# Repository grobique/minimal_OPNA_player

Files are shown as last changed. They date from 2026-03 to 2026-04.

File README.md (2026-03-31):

# minimal_OPNA_player
YM2608 (OPNA) player, using minimal amount of hardware to play PC98 music in .VGM and .S98 formats

## Overview
This is a **lightweight** (in current form) opensource project designed to interface a Yamaha YM2608 (OPNA) with an STM32F103C6T6 microcontroller, one of the cheapest ones. You can literally make it on a breadboard!

## Features
- Real hardware! As authentic as could be in "minimal" (also may known as "hell yeah")
- No need in external clock source!
- Micro SD card as a storage. Imagine how many tunes you can put in there!
- Basic components! Well, aside from YM2608 and its DAC, YM3016.
- Comments in (almost) ***EVERY SINGLE LINE*** of code!

## To do:
- Fix VGM tempo losses. These rush just a tiny bit, but I don't like it either way
- Put the libraries in here. Messing with preinstalled libs is... meh...

## Schematic
Refer to **[`schematic_v1.pdf`](./schematic_v1.pdf)** for pinouts and connections.

## Installation
Install ArduinoIDE, download STM32 core from [here](https://github.com/stm32duino/Arduino_Core_STM32), install [STM32CubeProg](https://www.st.com/en/development-tools/stm32cubeprog.html), install SdFat and GyverOLED libraries (available in library manager). Bam, done!
BEFORE flashing, make sure to edit SdFat configuration in `Documents\Arduino\libraries\SdFat\src\SdFatConfig.h`:
```
line 96 -  #define ENABLE_ARDUINO_SERIAL 0   will free some memory, allowing to disable Serial
line 169 - #define SPI_DRIVER_SELECT 2       will enable software SPI. i have no idea why SPI2 hangs the chip.
```
Yes, it reqires software SPI. I still have no idea why my microcontroller hangs dead when I'm trying to use hardware SPI2.

Compilation - Smallest (-Os) with LTO



## "Dumps", because I can.
Vorbis, quality 10, 88.2KHz.

[Sleeping Terror](https://drive.google.com/file/d/1qs6JLUKrdlb78_PDLtCmRrMHYK6tYY8U/view?usp=sharing) (gdrive)

## Contributing
please do.

## What's next?
I dunno lul. I wanna make a port to STM32F4 with several firmware versions. A PCB, for the love of our lord and saviour Shinki. Maybe I'll make it chew .M/.M2 files from Kajihara's driver. Since it's still plugged in my Line In, nothing stops me from making it a MIDI controlled synth. Hell yeah.

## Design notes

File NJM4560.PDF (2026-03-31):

# NJM4560

# MEMO

[CAUTION]
The specifications on this databook are only given for information , without any guarantee as regards either mistakes or omissions. The application circuits in this databook are described only to show representative usages of the product and not intended for the guarantee or permission of any right including the industrial rights.

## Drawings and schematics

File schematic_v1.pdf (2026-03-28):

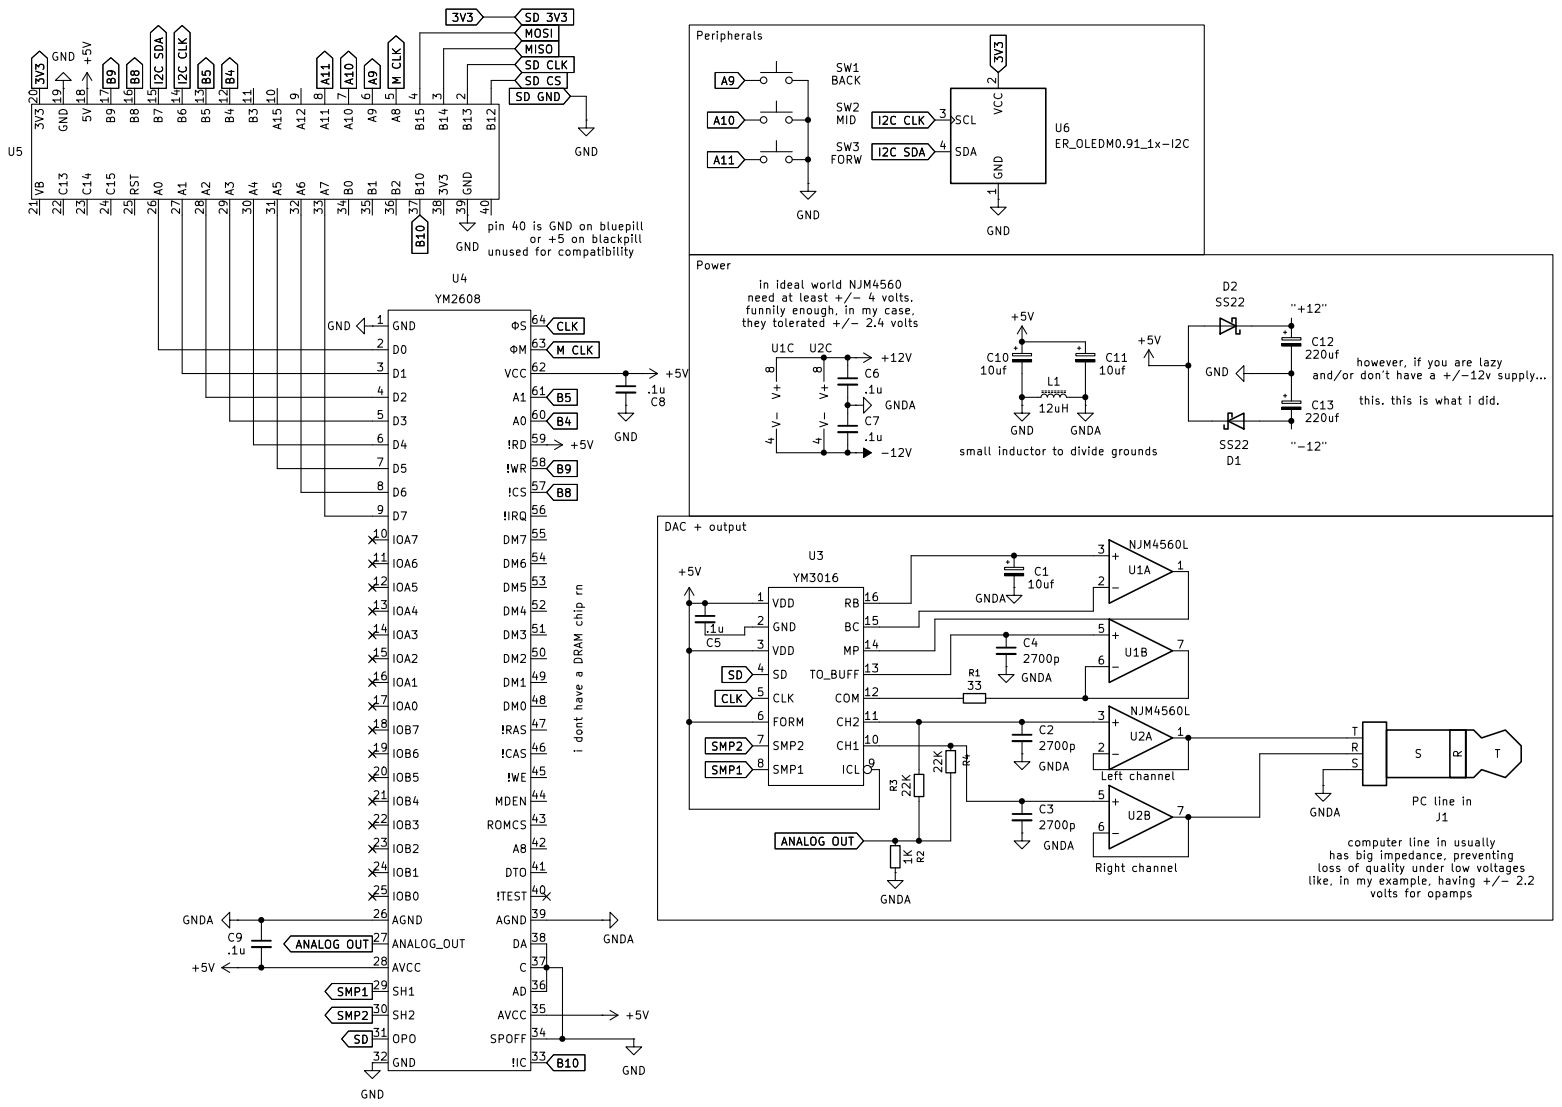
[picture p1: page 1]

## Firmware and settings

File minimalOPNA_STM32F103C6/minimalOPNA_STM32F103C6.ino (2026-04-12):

#include <Arduino.h>         
#include <SPI.h>             // thats for SdFat
#include <Wire.h>            // for I2C. just in case.
#include "SdFat.h"           // sd card stuff. i hope ya have one spare
#include <GyverOLED.h>       // Alex Gyver OLED library. lightweigh, reliable, fast enough

//      YM2608 pin setup
#define YM_A0   PB4  // YM2608 A0, for selecting register banks (port 0 or port 1)
#define YM_A1   PB5  // YM2608 A1, 0 - writing register data, 1 - write data
#define YM_CS   PB8  // YM2608 chip select pin, ACTIVE LOW
#define YM_WR   PB9  // YM2608 strobe pulse for writing data. ACTIVE LOW
#define YM_IC   PB10 // YM2608 initial clear, used as hardware reset. ACTIVE LOW

#define YM_RD   PB11 // YM2608 read *from* synth. basically, unused here, because i pulled it to VCC. ACTIVE LOW
// note: data bus is on PA0-PA7. these pins are in the same port, makes it easier to set them all with minimal latency. hardcoded a little below
// note: PA8 is a 8 MHz clock for YM2608. (mco)

//      software SPI setup (matches SPI2)
#define SD_CS_PIN   PB12 // sd chip select pin
#define SD_SCK_PIN  PB13 // clock 
#define SD_MISO_PIN PB14 // master in slave out
#define SD_MOSI_PIN PB15 // master out slave in
//                            !!!!!  ATTENTION  !!!!!
//                            DO THINGS BELOW! I SWEAR TO GOD
// \Documents\Arduino\libraries\SdFat\src\SdFatConfig.h:
// line 96 -  #define ENABLE_ARDUINO_SERIAL 0            will free some memory, allowing to disable Serial
// line 169 - #define SPI_DRIVER_SELECT 2                will enable software SPI. i have no idea why SPI2 hangs the chip.

// button setup
#define BTN_LEFT  PA9  // backwards
#define BTN_OK    PA10 // OK/back to menu button
#define BTN_RIGHT PA11 // forward

//      some globals and classes
// software spi class
SoftSpiDriver<SD_MISO_PIN, SD_MOSI_PIN, SD_SCK_PIN> mySoftSpi;
// setting up SdFat to use our software spi on 4 mhz clock
#define SD_CONFIG SdSpiConfig(SD_CS_PIN, DEDICATED_SPI, SD_SCK_MHZ(4), &mySoftSpi)

SdFat SD;       // main object for working with fat32
FsFile vgmFile; // file object with our track data

// OLED init
// using no buffer mode, saves 1K of RAM and reduces chances of lags
GyverOLED<SSD1306_128x64, OLED_NO_BUFFER> oled;

//      global variables
enum State { STATE_BROWSER, STATE_PLAY }; // two states - menu (list of tracks) and player
State currentState = STATE_BROWSER;       // main menu during bootup

bool isS98 = false;               // if true - S98 file is playing, if false - VGM is playing
uint32_t data_offset = 0x40;      // data offset where music data begins
uint32_t loop_offset = 0;         // offset where to jump when track ends
uint32_t s98_tick_us = 10000;     // single s98 tick length in microseconds

uint32_t current_samples = 0;     // sample counter to calculate track length in seconds (funnily enough, 44100 = 1s. nothing to do with *actual* discretization frequency of YM2608 (55.5K))
uint32_t total_samples = 0;       // VGM file length in samples
uint32_t current_us = 0;          // us counter for calculating the length of S98 file
uint32_t lastDrawTime = 0;        // last screen update timer

uint32_t track_sync_timer = 0;    // absolute timer, used to send data in YM2608 as precisely as i can

bool isPaused = false;            // pause flag. fun fact! it hangs notes, because YM2608 does not recieve a "note off" command
bool action_next = false;         // next track check
bool action_prev = false;         // prev track check
bool action_menu = false;         // middle button check

uint16_t totalFiles = 0;          // supported file counter in root dir
uint16_t fileIndex = 0;           // cursor index
uint16_t displayTopIdx = 0;       // for scrolling - shows the first file *displayed on screen*

char currentFilename[32] = "";       // track filename buffer
char metaTitle[21] = "Unknown Title"; // metadata track name buffer
char metaComposer[21] = "Unknown";    // metadata composer name buffer

//      some hardware stuff for YM2608

// setting up a clock signal for YM2608
void setupMCO() {
  // making a PA8 as push-pull, 50mhz
  GPIOA->CRH = (GPIOA->CRH & 0xFFFFFFF0) | 0x0000000B; 
  // enabling MCO, HSI, using external clock source (this shiny 8mhz cristal, in case of STM32F103. no, not the 32768hz one, thats realtime clock you silly goober)
  RCC->CFGR = (RCC->CFGR & ~(0x07 << 24)) | (0x05 << 24); 
}

//      pain kicks in
// sending data in YM2608 while trying to keep latencies from datasheet
void writeYM(uint8_t port, uint8_t reg, uint8_t data) {
  // stage 1 - choosing registers
  digitalWrite(YM_A1, port); // choosing port: 1 - FM1-FM3 + SSG + RSS, 0 - FM4-FM6 + ADPCM. YM2608 is YM2203(OPN) compatible, remember that?
  digitalWrite(YM_A0, LOW);  // "im gonna send you the register number address rn"
  
  // grabbing our port A, zeroing lower 8 bits, and writing register address
  GPIOA->ODR = (GPIOA->ODR & 0xFFFFFF00) | reg;
  delayMicroseconds(2); // setup time for volatges to settle

  digitalWrite(YM_CS, LOW);  // enbling the chip, making CS 0
  digitalWrite(YM_WR, LOW);  // making it WRITE data
  delayMicroseconds(2);      // giving some time to settle again
  digitalWrite(YM_WR, HIGH); // disbling data writing
  digitalWrite(YM_CS, HIGH); // disabling chip
  delayMicroseconds(4);      // approx. 17 clock cycles to apply the address

  // stage 2 - writing data in that register
  digitalWrite(YM_A0, HIGH); // "im sending the DATA to that address"
  GPIOA->ODR = (GPIOA->ODR & 0xFFFFFF00) | data; // writing port A data to send to YM2608
  delayMicroseconds(2); // settle time

  digitalWrite(YM_CS, LOW);  // enabling the chip
  digitalWrite(YM_WR, LOW);  // WRITING DATA
  delayMicroseconds(2);      // girls are preparing... please wait warmly
  digitalWrite(YM_WR, HIGH); // lowering the WRITE signal
  digitalWrite(YM_CS, HIGH); // releasing the chip in the wild
  delayMicroseconds(12);     // letting it proccess the audio data for approx. 83 clock cycles, as instructed in the datasheet
}

//      hardware reset
void resetYM() {
  digitalWrite(YM_IC, LOW);  // setting initial clear as 0, enabling it
  delay(20);                 // holding for a bit
  digitalWrite(YM_IC, HIGH); // and getting it back to 1, disabling
  delay(20);                 // giving it ome time to start
}

//      some button stuff
bool btn_l_last = HIGH, btn_ok_last = HIGH, btn_r_last = HIGH; // savestates for buttons, pulled up to HIGH interanally

//      checking the buttons, debounce included! (it sucks, millis() = UEEUGHH)
void checkButtons() {
  bool l = digitalRead(BTN_LEFT);  // reading LEFT button
  bool ok = digitalRead(BTN_OK);   // reading MIDDLE (aka OK/MENU, however ya call it m8) button
  bool r = digitalRead(BTN_RIGHT); // reading RIGHT button

  // if left btn got LOW and was HIGH                                                                                                             high does not mean "stoned" you doofus
  if (l == LOW && btn_l_last == HIGH) { action_prev = true; delay(50); } // falgging it and debouncing
  
  // middle button short press
  if (ok == LOW && btn_ok_last == HIGH) { 
    if (currentState == STATE_BROWSER) action_menu = true; // if in menu - plays selected file
    else {
      isPaused = !isPaused;                             // if in player - play/pause
      delay(50); 
      if (!isPaused) {
        track_sync_timer = micros();      // debounce delay compensation
        lastDrawTime = millis();
      }
    }
  }
  
  // long middle button press
  if (ok == LOW && currentState == STATE_PLAY) {
    uint32_t holdTime = millis(); // hold timer start
    while(digitalRead(BTN_OK) == LOW) { // while it pressed:
      if (millis() - holdTime > 700) {  // and .7s passed
        action_menu = true;             // going back to menu
        break;                          // exiting the cycle!
      }
    }
  }

  // right button press
  if (r == LOW && btn_r_last == HIGH) { action_next = true; delay(50); }

  // saving states for next function call
  btn_l_last = l; btn_ok_last = ok; btn_r_last = r;
}

//      pain 2: electric boogaloo
//      synchronization
// this changes delay() function, except it does not block anything
void syncWaitUs(uint32_t us) {
  // infinite cycle, while system micros() timer and our target timer are less than our required delay
  while ((micros() - track_sync_timer) < us) {
    checkButtons(); // as we are waiting, we need to check how buttons are doing
    // if a button is pressed, breaking the pause
    if (action_next || action_prev || action_menu) return;
  }
  // adding that pause to our absolute timer
  track_sync_timer += us;
}

//      file and meta reading procedures

// reads two bytes to shove them in a single 32bit number
uint32_t read32() {
  uint32_t val = 0;
  vgmFile.read(&val, 4);
  return val;
}

// reading GD3 tags. these are used in VGMs
void readGD3String(char* buf, int maxLen) {
  int i = 0;
  while (true) {
    // GD3s are saven in UTF-16
    uint16_t c = vgmFile.read() | (vgmFile.read() << 8);
    if (c == 0x0000) { buf[i] = '\0'; break; } // two 00 bytes - end of line
    // reading only ASCII symbols
    if (i < maxLen - 1) { buf[i] = (char)(c & 0xFF); i++; }
  }
}

// S98 tag reader
void parseS98Tags(uint32_t tag_offset) {
  // clearing buffers
  strcpy(metaTitle, "Unknown");
  strcpy(metaComposer, "Unknown");
  if (tag_offset == 0) return; // if offset is 0, there's no tags, exiting
  
  vgmFile.seek(tag_offset); // jumping straight to tag block
  char buf[5];
  vgmFile.read(buf, 5); // reading our 5 byte marker closer to the end, [S98]
  if (strncmp(buf, "[S98]", 5) != 0) return; // if its not "[S98]", tags might be corrupted, exiting

  char line[64]; // one line buffer, 64 symbols
  while (vgmFile.available()) {
    int i = 0;
    while (vgmFile.available() && i < 63) { // reading 63 of them
      char c = vgmFile.read(); // taking 1 symbol
      if (c == '\n' || c == '\r') { // if we got line feed
        if (i == 0) continue; // skiping empty symbols
        else break;           // if the string isnt empty, exiting
      }
      line[i++] = c; // saving a symbol to a buffer
    }
    line[i] = '\0'; // closing a string with a zero byte. its not me, its C
    if (i == 0) break; // if we didnt read anything, then its end of file

    // if our string starts with "title="
    if (strncmp(line, "title=", 6) == 0) {
      strncpy(metaTitle, line + 6, 20); metaTitle[20] = '\0'; // copying everything in title buffer
    } 
    // same for composer
    else if (strncmp(line, "artist=", 7) == 0 || strncmp(line, "composer=", 9) == 0) {
      int offset = (line[0] == 'a') ? 7 : 9; // calculating the offset
      strncpy(metaComposer, line + offset, 20); metaComposer[20] = '\0'; // and copying in metaComposer
    }
  }
}

// counting the musical tracks here. once per boot
void scanFilesCount() {
  FsFile dir; dir.open("/"); // looking up what do we have in root
  FsFile file;
  totalFiles = 0; // zeroing the counter
  while (file.openNext(&dir, O_READ)) { // looking for files
    if (!file.isHidden() && !file.isDir()) { // ignoring folders and hidden stuff
      char name[32]; file.getName(name, sizeof(name)); // reading file name...
      // ...and exension. if .vgm or .s98, adding 1 to a counter
      if (strstr(name, ".vgm") || strstr(name, ".VGM") || strstr(name, ".s98") || strstr(name, ".S98")) totalFiles++;
    }
    file.close(); // closing file, picking up next one
  }
  dir.close(); // closing the folder
}
//      draw calls for OLED

// drawing main menu with our list of files
void drawBrowser() {
  oled.clear(); // screen clear
  oled.home();  // carriage goes in top left
  oled.print(F("== SELECT TRACK ==")); // header
  
  FsFile dir; dir.open("/"); // reading root
  FsFile file;
  uint16_t count = 0;

  // stage one - scrolling and looking for the first file thats being drawn
  while (file.openNext(&dir, O_READ)) {
    if (!file.isHidden() && !file.isDir()) {
      char name[32]; file.getName(name, sizeof(name));
      if (strstr(name, ".vgm") || strstr(name, ".VGM") || strstr(name, ".s98") || strstr(name, ".S98")) {
        if (count == displayTopIdx) break; // found it, closing the cycle (the file is STILL BEING OPEN)
        count++;
      }
    }
    file.close(); // closing the file, looking for the next one
  }

  // stage 2 - drawing 6 rows of files
  for (int i = 0; i < 6; i++) {
    if (!file.isOpen()) break; // if no more files - exiting
    char name[32]; file.getName(name, sizeof(name)); // grabbing file name
    
    oled.setCursor(0, i + 1); // carriage goes to rows 1 and 6
    
    // drawing a simple cursor next to selected file
    if (displayTopIdx + i == fileIndex) oled.print(F(">"));
    else oled.print(F(" ")); // or else drawing a space
    
    oled.print(name); // printing a file name
    file.close(); // closing the file

    // small cycle to see a next file for the list
    while (file.openNext(&dir, O_READ)) {
      if (!file.isHidden() && !file.isDir()) {
        char nextName[32]; file.getName(nextName, sizeof(nextName));
        if (strstr(nextName, ".vgm") || strstr(nextName, ".VGM") || strstr(nextName, ".s98") || strstr(nextName, ".S98")) break; 
      }
      file.close();
    }
  }
  dir.close(); // closing directory
}

// drawing time! every second
void drawPlayer() {
  if (millis() - lastDrawTime < 1000) return; // if 1s didnt pass yet - exiting
  lastDrawTime = millis(); // refreshing draw call timer

  oled.setCursor(0, 6); // moving our carriage to a row 6

  if (!isS98) { // if we are playing the vgm file
    uint32_t curSec = current_samples / 44100; // counting seconds that passed
    uint32_t totSec = total_samples / 44100;   // calculating track length
    
    // drawing time (mm:ss)
    oled.print(curSec / 60); oled.print(F(":")); 
    if ((curSec % 60) < 10) oled.print(F("0")); // sneakily adding a 0, if <10 seconds were played
    oled.print(curSec % 60);
    
    oled.print(F(" / "));
    
    // track length
    oled.print(totSec / 60); oled.print(F(":"));
    if ((totSec % 60) < 10) oled.print(F("0")); 
    oled.print(totSec % 60);
  } else { // if S98 is being played...
    uint32_t curSec = current_us / 1000000; // calculating from microseconds
    
    // i already forgot wht was i doing here, i think .s98 doesnt have track length stored in it. but at least we can count current time. im sowwy
    oled.print(curSec / 60); oled.print(F(":")); 
    if ((curSec % 60) < 10) oled.print(F("0")); 
    oled.print(curSec % 60);
    oled.print(F(" / --:--"));
  }
  
  oled.print(F("       ")); // drawing spaces to erase some stuff that could appear
}

//    starting the track
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
void loop() {
  checkButtons(); // checking how our buttons are doing

//      branch 1 - main meny, aka file list
  if (currentState == STATE_BROWSER) {
    if (action_prev) { // on LEFT press...
      if (fileIndex > 0) fileIndex--; // moving cursor up
      if (fileIndex < displayTopIdx) displayTopIdx = fileIndex; // scrolling up, if needed
      drawBrowser(); // redrawing
    }
    if (action_next) { // on RIGHT press...
      if (fileIndex < totalFiles - 1) fileIndex++; // moving cursor down
      if (fileIndex >= displayTopIdx + 6) displayTopIdx = fileIndex - 5; // scrolling down if needed
      drawBrowser(); // redrawing
    }
    if (action_menu) playSelectedFile(); // on OK press - playing selected file
    
    // resetting button flags
    action_next = action_prev = action_menu = false;
    return; // going back to beginning of loop()
  }

//          branch 2 - player loop
  if (currentState == STATE_PLAY) {
    
    // if you are *holding* MIDDLE button...
    if (action_menu) { 
      resetYM(); // muting
      currentState = STATE_BROWSER; // returning to menu
      drawBrowser(); // and drawing it
      action_next = action_prev = action_menu = false; 
      return;
    }
    
    // if you press RIGHT while playing, play next file
    if (action_next) { fileIndex = (fileIndex + 1) % totalFiles; playSelectedFile(); action_next = false; return; }
    // if you press LEFT while playing, play previous file
    if (action_prev) { fileIndex = (fileIndex > 0) ? fileIndex - 1 : totalFiles - 1; playSelectedFile(); action_prev = false; return; }

    // if we are paused
    if (isPaused) {
      drawPlayer(); // updating the time
      track_sync_timer = micros(); 
      return;
    }
    drawPlayer(); // drawcall

    // reading commands from file!
    int c = vgmFile.read();
    if (c < 0) { // if file is finished...
      if (loop_offset != 0) vgmFile.seek(loop_offset); // looking for a loop point.
      else { resetYM(); writeYM(0, 0x29, 0x80); vgmFile.seek(data_offset); current_samples = 0; current_us = 0; } // if theres none - jumping to beginning of file
      track_sync_timer = micros(); // resetting timer
      return; 
    }
    
    uint8_t cmd = c; // command to execute by YM2608 

//          s98 parser
    if (isS98) { 
      switch(cmd) {
        case 0x00: writeYM(0, vgmFile.read(), vgmFile.read()); break; // 0x00 = writing in port 0. aka OPN compatibility, FM1-FM3, SSG, and timers
        case 0x01: writeYM(1, vgmFile.read(), vgmFile.read()); break; // 0x01 = writing in port 1, aka FM4-FM6, ADPCM and RSS
        
        case 0xFF: // 1 tick pause
          current_us += s98_tick_us; // incrementing the counter
          syncWaitUs(s98_tick_us);   // waiting for one tick
          break;
          
        case 0xFE: // looooong pause with N ticks, pretty tricky
          {
            uint32_t n = 0; uint8_t shift = 0, b;
            do { b = vgmFile.read(); n |= (b & 0x7F) << shift; shift += 7; } while (b & 0x80); // unpacking pause length
            uint32_t delay_time = (n + 2) * s98_tick_us; // formula from S98 specs
            current_us += delay_time; 
            syncWaitUs(delay_time); // waiting for calculated amount of time
          } break;
          
        case 0xFD: // marker of end of track / loop
          if (loop_offset != 0) vgmFile.seek(loop_offset);
          else { resetYM(); writeYM(0, 0x29, 0x80); vgmFile.seek(data_offset); current_us = 0;}
          track_sync_timer = micros(); // preventing loss of tempo
          break;
          
        default: 
          if (cmd < 0x7F) { vgmFile.read(); vgmFile.read(); } // skipping any other chip aside YM2203 and YM2608
          break;
      }
    } 

//          VGm parser

    else { 
      switch (cmd) {
        // writing in port 0(0x51=OPN, 0x54/0x56=OPNA)
        case 0x51: case 0x54: case 0x56: writeYM(0, vgmFile.read(), vgmFile.read()); break;
        // writing in port 1 (0x55/0x57=OPNA)
        case 0x55: case 0x57: writeYM(1, vgmFile.read(), vgmFile.read()); break;
        
        // 0x61 - waiting for some amount of samples
        case 0x61: { 
            uint16_t s; vgmFile.read(&s, 2); // reading 2 bytes of lengh
            current_samples += s;            // adding to a timer
            syncWaitUs(( (uint32_t)s * 10000 ) / 441);              // 1 sample @ 44.1кГц ≈ 22.6 us (evading any floating point operations to preserve precision, syncWaitUs will compesate. syncWaitUs <3)
          } break;
          
        // 0x62: waiting EXACTLY 1/60th of a second (NTSC)
        case 0x62: current_samples += 735; syncWaitUs(16667); break;
        
        // 0x63: waiting EXACLTY 1/50th of a second (PAL)
        case 0x63: current_samples += 882; syncWaitUs(20000); break;
        
        // 0x66: end of file / loop
        case 0x66: 
          if (loop_offset != 0) vgmFile.seek(loop_offset);
          else { resetYM(); writeYM(0, 0x29, 0x80); vgmFile.seek(data_offset); current_samples = 0; }
          track_sync_timer = micros(); // loss of tempo prevention hotline
          break;
          
        // 0x67 - ADPCM samples
        case 0x67: { 
            uint32_t skip_start_time = micros(); //timestamp for compensating SD read latencies when jumping through ADPCM block, which is currently unused

            vgmFile.read(); // skipping 0x66 marker
            vgmFile.read(); // skipping memory type
            uint32_t sz = read32(); // reading sample block file
            vgmFile.seek(vgmFile.position() + sz); // skipping all of that, I DONT HAVE A DRAM CHIP UUUUWAAAAAAAHHHHHHHHHHH

            track_sync_timer += (micros() - skip_start_time); //kinda "forgiving" that jump time, so tempo wont float away.
          } break;                                            //yes, i have no idea either, wtf is even going on
          
        // skipping unknown commands
        default:
          if (cmd >= 0x70 && cmd <= 0x7F) { // 0x70-0x7F: short pause (last 4 bits + 1) samples
            uint8_t w = (cmd & 0x0F) + 1; current_samples += w; syncWaitUs(( (uint32_t)w * 10000 ) / 441); 
          }
          // if we dont know a command, doing nothing
          else if (cmd >= 0x30 && cmd <= 0x3F) vgmFile.read(); // 1 byte command
          else if (cmd >= 0x40 && cmd <= 0x4F) { vgmFile.read(); vgmFile.read(); } // 2 byte command
          else if (cmd >= 0x50 && cmd <= 0x5F) { vgmFile.read(); vgmFile.read(); } 
          else if (cmd >= 0xA0 && cmd <= 0xBF) { vgmFile.read(); vgmFile.read(); }
          else if (cmd >= 0xC0 && cmd <= 0xDF) { vgmFile.read(); vgmFile.read(); vgmFile.read(); } // 3 byte command
          else if (cmd >= 0xE0 && cmd <= 0xFF) { read32(); } // 4 byte command
          break;
        } //                    and we are gaming. or idk
      }
    }
  }

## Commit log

2026-03-29 Add files via upload
    fixed VGM tempo loss
    [minimalOPNA_STM32F103C6.ino]
2026-03-29 Refactor syncWaitUs for sample timing precision
    Updated syncWaitUs calculation to avoid floating point operations for precision.
    [minimalOPNA_STM32F103C6.ino]
